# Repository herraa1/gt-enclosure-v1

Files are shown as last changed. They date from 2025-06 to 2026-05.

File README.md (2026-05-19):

# Acrylic Enclosure for the Gigatron TTL microcomputer

## Introduction

The [Gigatron TTL microcomputer](https://gigatron.io/) by Marcel van Kervinck and Walter Belgers is a minimalistic retro computer without a microprocessor chip.

The original Gigatron TTL microcomputer was sold as a kit with a wooden enclosure, but that original enclosure is no longer available anymore.

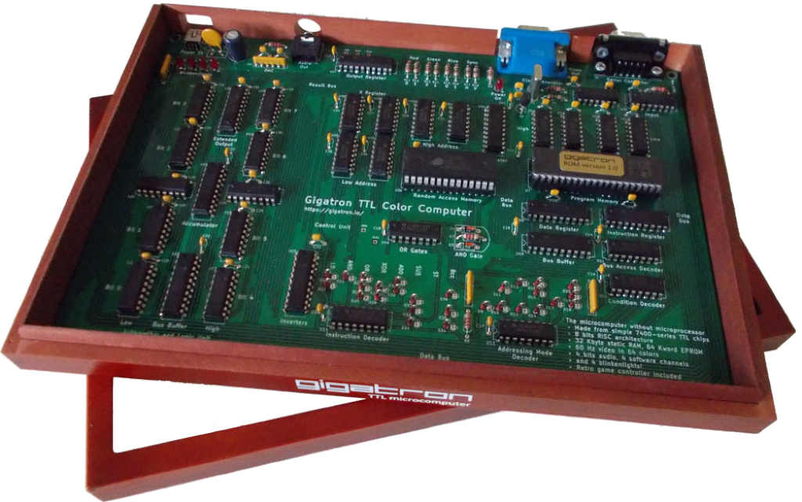
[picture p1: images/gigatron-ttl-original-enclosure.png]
[](images/gigatron-ttl-original-enclosure.png)

This acrylic enclosure has been designed to replace the original wooden enclosure while keeping its overall look and feel.

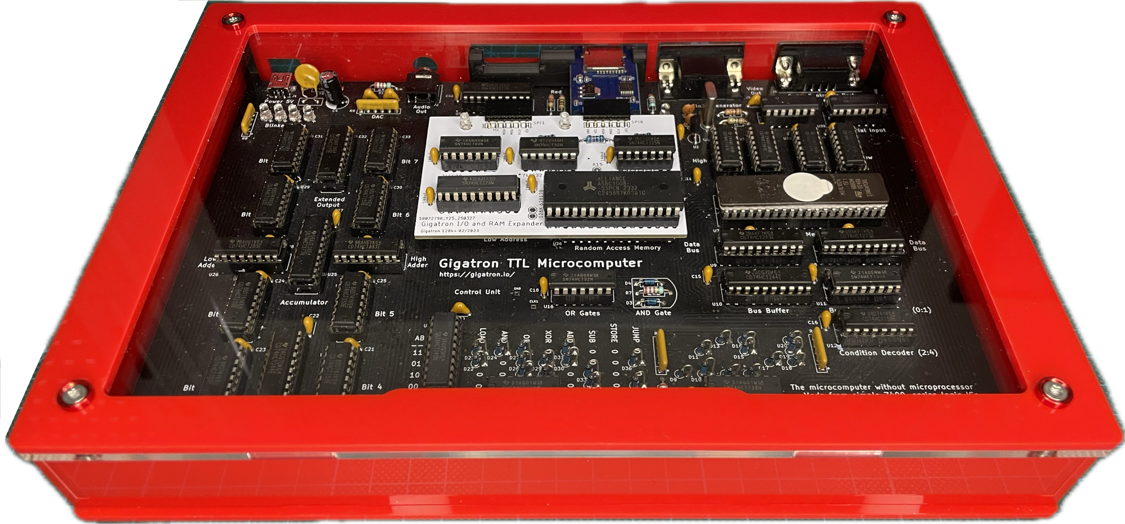
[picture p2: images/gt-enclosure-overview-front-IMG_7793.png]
[](images/gt-enclosure-overview-front-IMG_7793.png)

## Features

* Transparent top layer to expose the Gigatron TTL microcomputer
* Open holes for all original Gigatron TTL connectors (power, audio, video, joystick)
* Compatible with the [Gigatron I/O and RAM expander](https://hackaday.io/project/164176-gigatron-io-and-ram-expander), specifically tested with [hans61 Dual Drive 128K Expansion](https://github.com/hans61/Gigatron-TTL/tree/main/Expansion128k)
* Only 4 screws needed to open and get access to the Gigatron TTL microcomputer

## [Enclosure](enclosure/)

The enclosure is designed for 3mm acrylic sheets and must be cut by laser for optimal results.

There is a set of colored pieces (`Bottom`, `Left`, `Right`, `Front`, `Back` and `Top bezel`) and one transparent piece (`Top (transparent)`).

* [gigatron-ttl-acrylic-case-v1b-3mm-438x254-red-ready-to-lasercut.dxf](enclosure/gigatron-ttl-acrylic-case-v1b-3mm-438x254-red-ready-to-lasercut.dxf)
* [gigatron-ttl-acrylic-case-v1b-3mm-dina4-transparent-ready-to-lasercut.dxf](enclosure/gigatron-ttl-acrylic-case-v1b-3mm-dina4-transparent-ready-to-lasercut.dxf)

## Building the enclosure

### Required material

* 3mm colored acrylic sheet (at least 438mm x 254mm)
* 3mm DINA4 transparent acrylic sheet
* 4x 6+6mm M3 female-male hex standoffs
* 4x 22mm M3 female-female hex standoffs
* 8x M3 aluminum washer for countersunk screws
* 4x 10mm M3 countersunk screws
* 4x 12mm M3 countersunk screws

### Assembly instructions

1. Use the provided [CAD design files](enclosure/) to have the acrylic sheets cut by laser into the required parts.

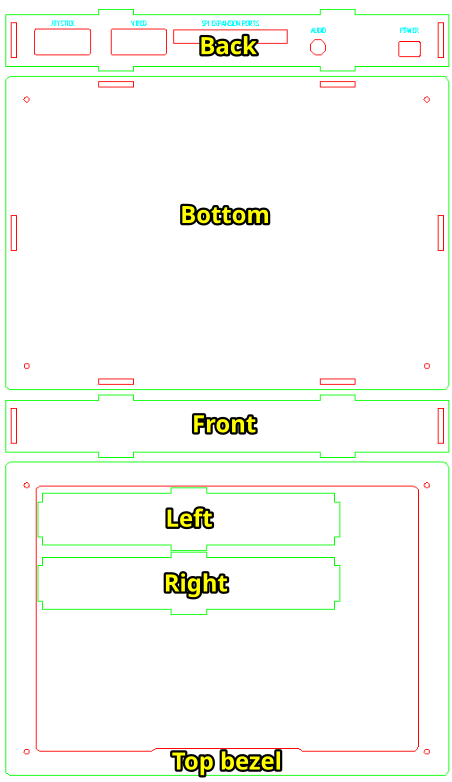
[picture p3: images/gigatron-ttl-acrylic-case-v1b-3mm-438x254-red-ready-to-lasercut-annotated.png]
[](images/gigatron-ttl-acrylic-case-v1b-3mm-438x254-red-ready-to-lasercut-annotated.png)
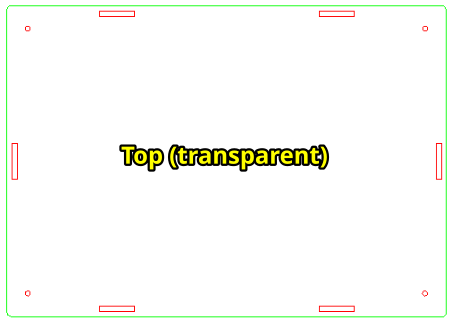
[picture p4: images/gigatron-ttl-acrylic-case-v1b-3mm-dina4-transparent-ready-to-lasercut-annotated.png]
[](images/gigatron-ttl-acrylic-case-v1b-3mm-dina4-transparent-ready-to-lasercut-annotated.png)

2. Peel the plastic protections from all the acrylic parts.

3. Start by inserting four M3 10mm countersunk screws with their respective washers spacers on the `Bottom` part from the outside to the inside. Add a bit of bluetak or tape to secure the screws on the outside as you will need now to turn the `Bottom` part upside down.

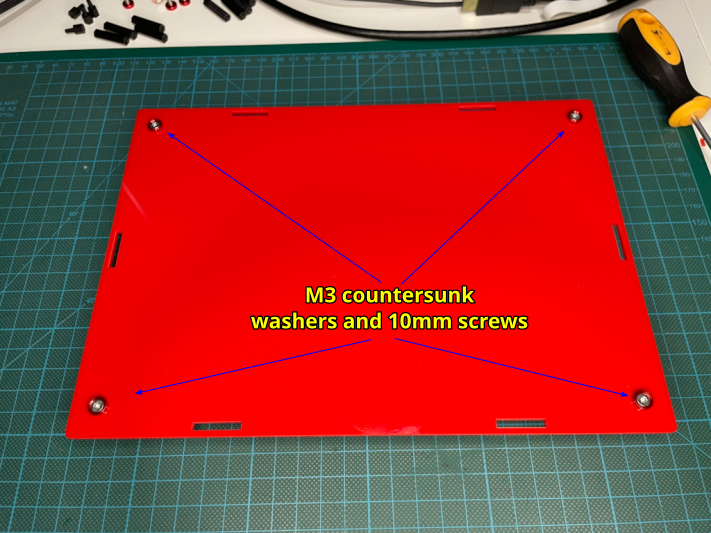
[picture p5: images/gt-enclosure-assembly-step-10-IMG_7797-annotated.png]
[](images/gt-enclosure-assembly-step-10-IMG_7797-annotated.png)

4. Turn the `Bottom`part so that the interior side now looks upwards, and screw on the inside the four M3 6+6mm female-male hex standoffs to the M3 10mm countersunk screws that you just inserted.

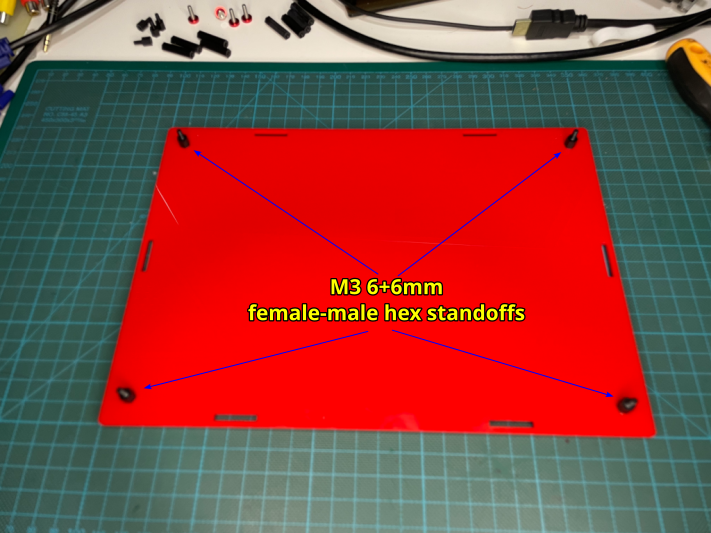
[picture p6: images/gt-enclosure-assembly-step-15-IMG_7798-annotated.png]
[](images/gt-enclosure-assembly-step-15-IMG_7798-annotated.png)

5. Slide in the Gigatron TTL microcomputer PCB aligning the PCB holes with the male side of the M3 6+6mm hex standoffs.

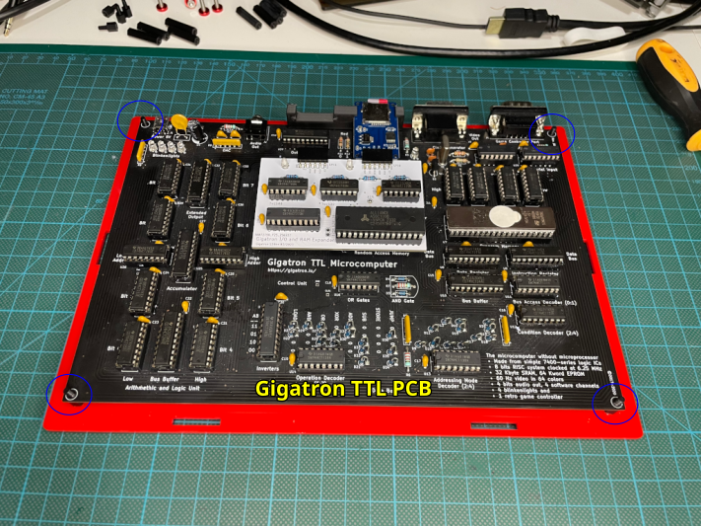
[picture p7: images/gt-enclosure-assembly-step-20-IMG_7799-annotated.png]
[](images/gt-enclosure-assembly-step-20-IMG_7799-annotated.png)

6. Screw the four M3 22mm hex female standoffs on top of the Gigatron TTL microcomputer PCB to the male side of the M3 6+6mm hex standoffs.

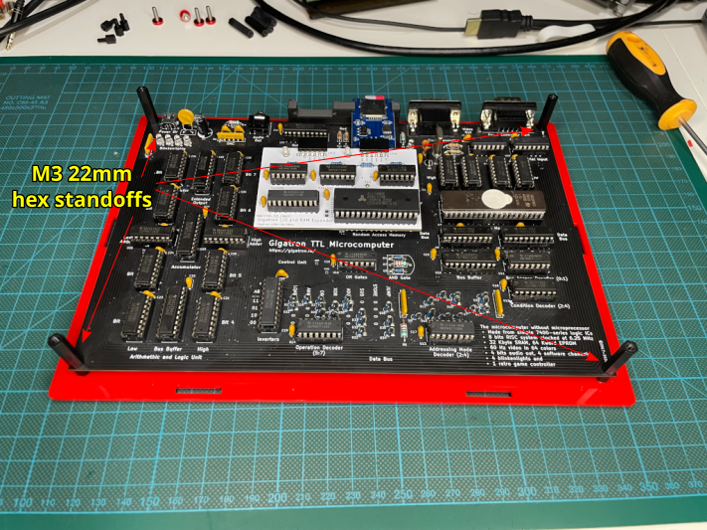
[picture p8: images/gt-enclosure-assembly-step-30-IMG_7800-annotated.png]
[](images/gt-enclosure-assembly-step-30-IMG_7800-annotated.png)

7. Add the `Back`, `Left`, `Right`and `Front` parts of the enclosure, snapping them to the `Bottom` part and between them.

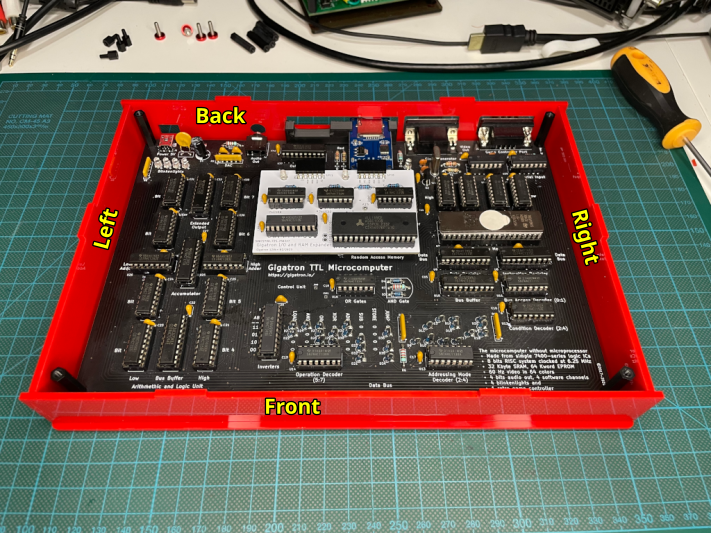
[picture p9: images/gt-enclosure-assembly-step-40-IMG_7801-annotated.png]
[](images/gt-enclosure-assembly-step-40-IMG_7801-annotated.png)

8. Insert the `Top (transparent)` part into the already formed enclosure. Do not use screws yet.

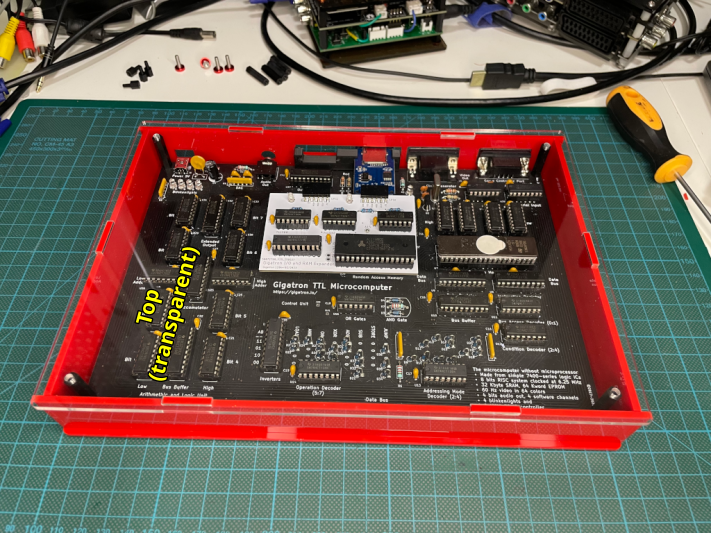
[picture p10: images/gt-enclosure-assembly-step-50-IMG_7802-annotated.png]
[](images/gt-enclosure-assembly-step-50-IMG_7802-annotated.png)

9. Finally, add the `Top bezel` part on top of the `Top (transparent)` part and align their holes (both parts) to the M3 22mm hex female standoff holes. Use the remaining washers and 12mm screws to securely close the enclosure.

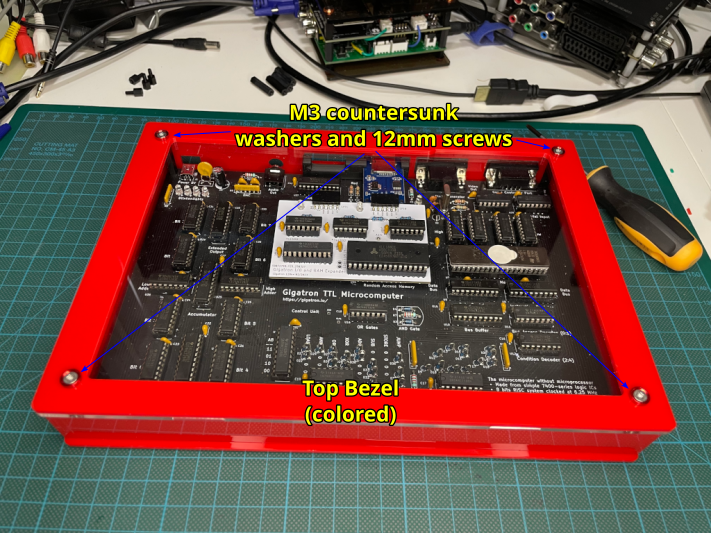
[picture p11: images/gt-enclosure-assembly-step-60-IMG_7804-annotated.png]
[](images/gt-enclosure-assembly-step-60-IMG_7804-annotated.png)

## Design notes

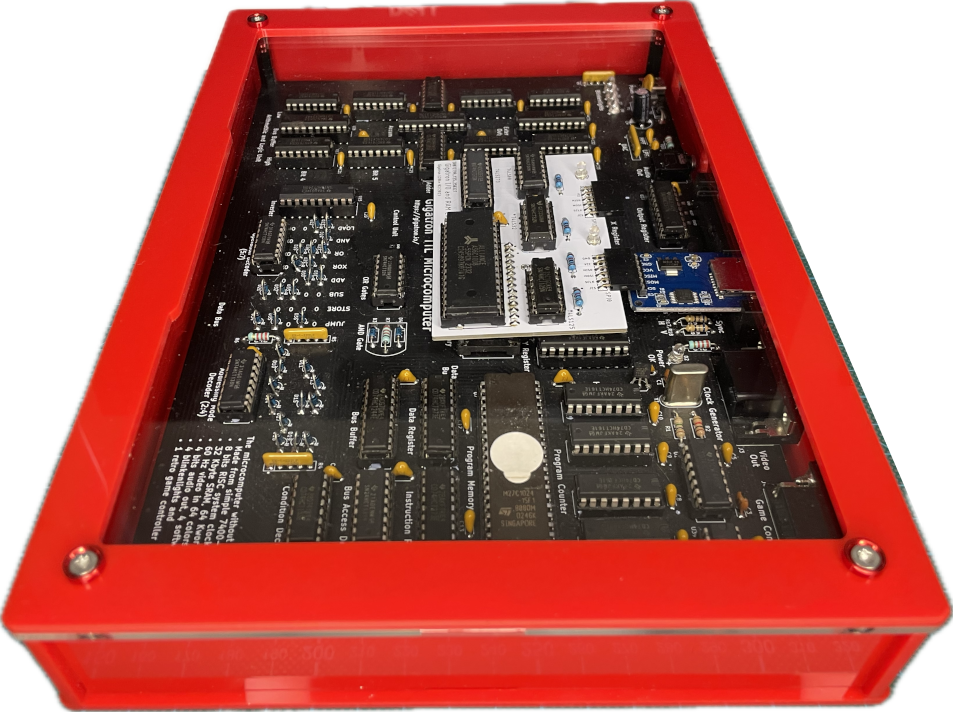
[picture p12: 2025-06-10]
images/gt-enclosure-overview-right-IMG_7794.png

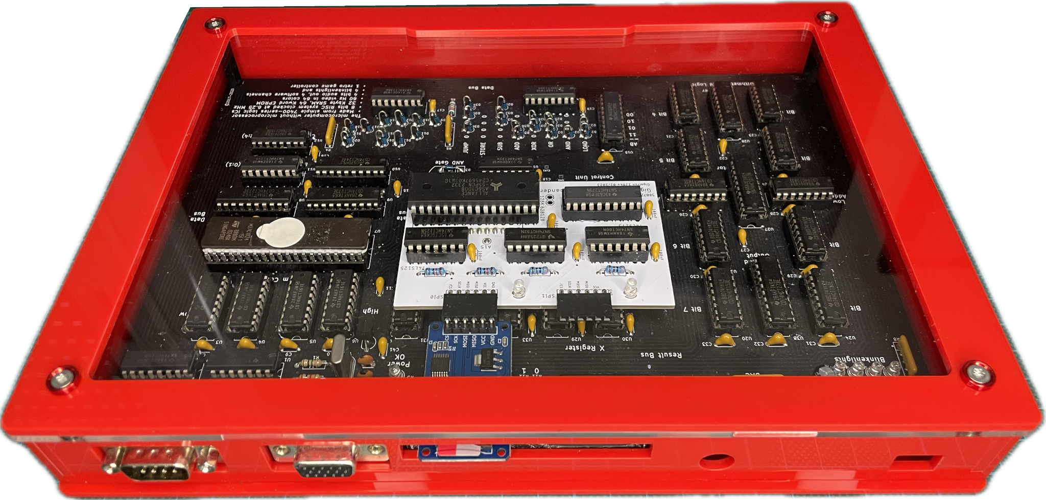
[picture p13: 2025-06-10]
images/gt-enclosure-overview-back-IMG_7795.png

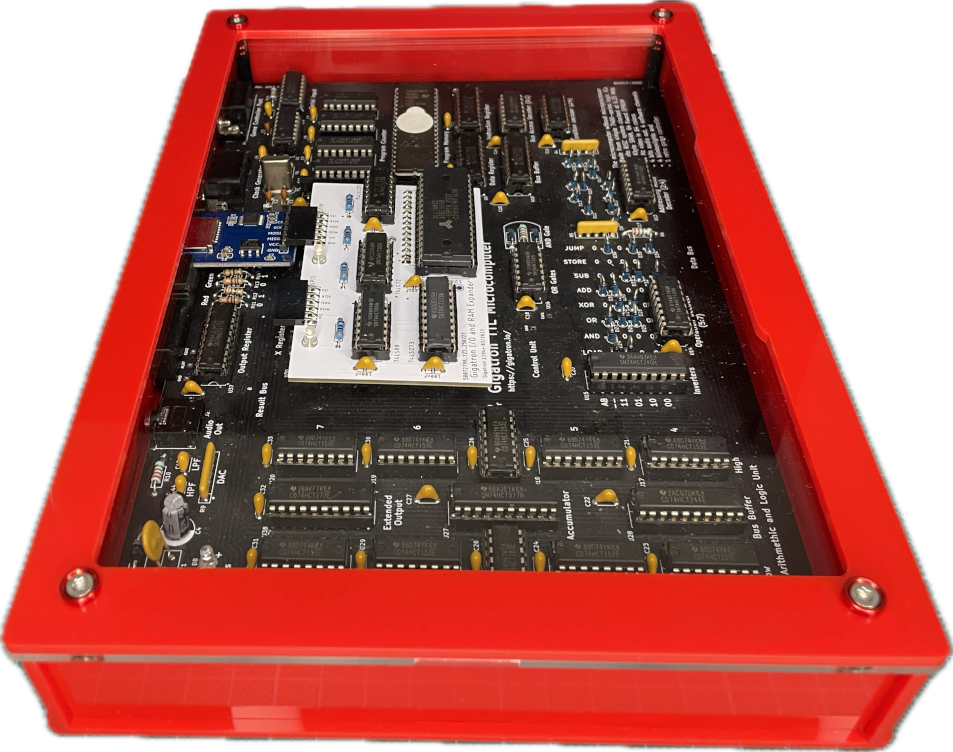
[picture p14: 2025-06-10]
images/gt-enclosure-overview-left-IMG_7796.png

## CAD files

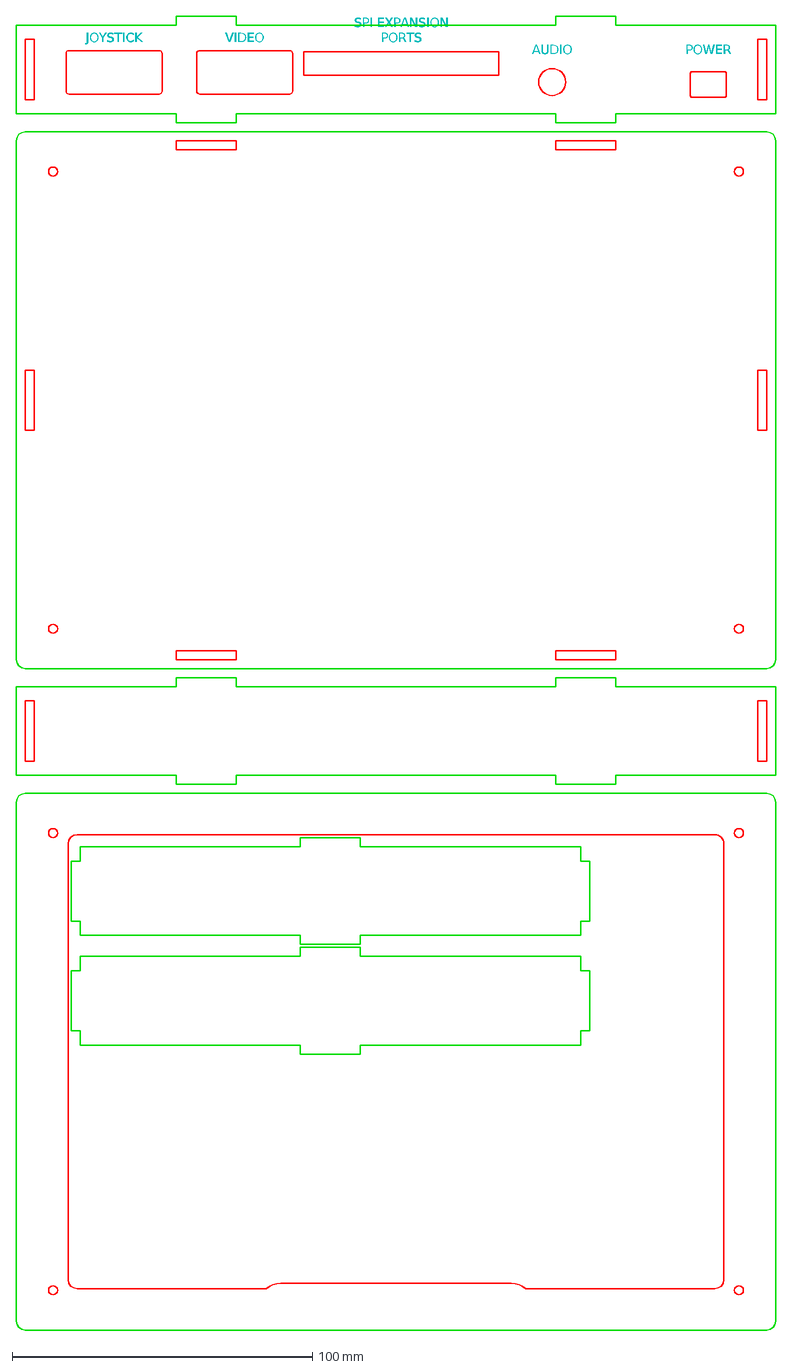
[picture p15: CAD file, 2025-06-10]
enclosure/gigatron-ttl-acrylic-case-v1b-3mm-438x254-red.dxf
JOYSTICK
VIDEO
SPI EXPANSION PORTS
AUDIO
POWER

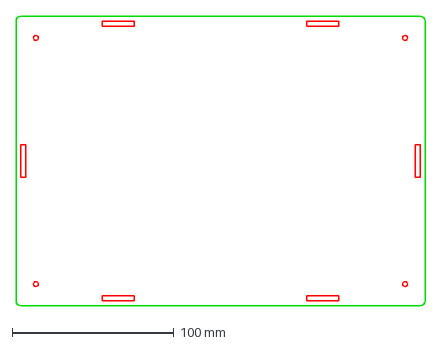
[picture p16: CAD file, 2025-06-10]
enclosure/gigatron-ttl-acrylic-case-v1b-3mm-dina4-transparent-ready-to-lasercut.dxf
253.1 x 178.9 mm

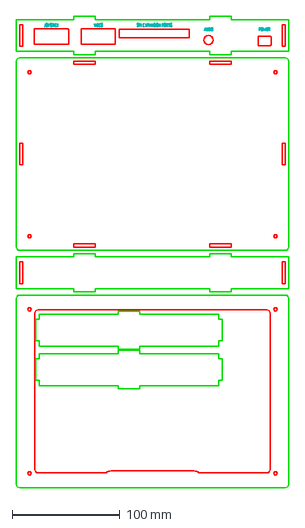
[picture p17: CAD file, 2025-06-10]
enclosure/gigatron-ttl-acrylic-case-v1b-3mm-438x254-red-ready-to-lasercut.dxf
253.1 x 438.0 mm
